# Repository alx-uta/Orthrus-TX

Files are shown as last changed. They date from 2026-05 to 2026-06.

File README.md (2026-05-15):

# Orthrus-TX

OrthrusTx is a custom high-performance RC transmitter platform built around the STM32H745 microcontroller and designed specifically for modern ExpressLRS-based systems. The project focuses on low-latency control, clean mixed-signal hardware design, modular RF integration, and long-term expandability without unnecessary complexity.

The hardware architecture separates critical analog, digital, and RF sections across an 8-layer PCB stackup to improve signal integrity and reduce noise coupling.

## Features

- STM32H745ZIT6 dual-core MCU
- Dual independent ExpressLRS interfaces
- Modular RF daughterboard design
- Precision filtered analog joystick inputs
- USB connectivity
- SD card support
- Rotary encoders and configurable inputs
- Dedicated analog and digital power domains
- Low-noise mixed-signal PCB layout
- Replaceable battery-oriented design

## Design Goals

OrthrusTx prioritizes:

- Low latency
- High reliability
- Electrical cleanliness
- Modular hardware architecture
- Repairability

## Project Vision

OrthrusTx is being developed both as a functional long-range RC transmitter and as a deep embedded hardware/software engineering project focused on performance, architecture, signal integrity, and system-level design.

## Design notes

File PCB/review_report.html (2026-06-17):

# Orthrus-TX — PCB Design Review Report

RC Radio Transmitter Controller | 8-Layer Impedance-Controlled PCB

Project

Orthrus-TX v1.0.0

Schematic Date

2026-03-29

Gerbers Generated

2026-05-19

KiCad Version

10.0.2

Board Size

49.1 × 49.1 mm

Thickness

1.613 mm

Layers

8 (Imp. Ctrl.)

Target Fab

JLCPCB / PCBWay

0

Critical

2

High

4

Medium

5

Low / Info

14

Checks Passed

📋

## Board Overview

Platform: RC Radio Transmitter controller based on STM32H745ZIT6 dual-core Arm Cortex-M7/M4.

Key Interfaces: USB-C (USB 2.0 FS), 2× ELRS RF module connectors, 2× Joystick connectors (6-pin), 2× Encoder connectors (8-pin), Analog potentiometer connector, Digital potentiometer connector, SWD programming header, Battery power input.

Power System: Battery input → reverse-polarity protection (AO3407A P-FET + D1 Schottky) → VCC rail → 4× AP2112K-3.3 LDO (600 mA each) → 3.3 V rails (LD1–LD4). STM32H745 internal SMPS (L1 = 2.2 µH) used for core supply.

EMC: DLW21SN900SQ2L CMC on USB data lines, BLM18AG102SN1D ferrite bead on USB/analog power, 7× SRV05-4 TVS arrays on I/O.

Layer | Name | Cu µm | Diel mm | εr
L1 | F.Cu — SIG TOP | 35 | — | —
— | Prepreg | — | 0.421 | 4.40
L2 | In1.Cu — GND | 30 | — | —
— | Core | — | 0.075 | 3.99
L3 | In2.Cu — POWER | 30 | — | —
— | Prepreg | — | 0.138 | 3.91
L4 | In3.Cu — GND | 30 | — | —
— | Core | — | 0.075 | 3.99
L5 | In4.Cu — ELRS | 30 | — | —
— | Prepreg | — | 0.138 | 3.91
L6 | In5.Cu — GND | 30 | — | —
— | Core | — | 0.075 | 3.99
L7 | In6.Cu — ANALOG | 30 | — | —
— | Prepreg | — | 0.421 | 4.40
L8 | B.Cu — GND | 35 | — | —

Total board thickness: 1.613 mm | Impedance controlled

⚡

## Power Architecture Review

LOW AP2112K-3.3 LDO Dropout at End-of-Discharge — Acts as Implicit Low-Battery Protection LD1–LD4

The AP2112K-3.3 has a worst-case dropout voltage of 300–600 mV at 600 mA, meaning VIN must be ≥ 3.6 V to maintain regulated 3.3 V output. A 1S LiPo discharges from 4.2 V to a hard protection cut-off of ~3.0 V. Below VIN = 3.6 V the LDO output tracks VIN − VDO — the MCU will brownout-reset at approximately VCC ≈ 3.0–3.3 V, which is well above the battery’s 3.0 V over-discharge threshold.

This behaviour acts as implicit low-battery protection: the transmitter will fail-safe (MCU resets) before the battery is deeply discharged. No hardware change is required. Note: the KiCad symbol description states “3.8V–6V input voltage range” — the actual datasheet VIN(min) is 2.5 V; the 3.8 V figure is a worst-case start-up guideline from an application note (see also L1).

Recommended firmware enhancement: Monitor VCC via an MCU ADC input (resistor divider from VCC to a 3.3 V ADC-safe level) and alert the user — LED, display, or telemetry — when VCC drops below ~3.7 V. This provides advance warning before LDO dropout, preventing unexpected mid-flight power loss. Ensure any NVM or flash write operations complete before VCC falls to 3.3 V to avoid data corruption.

HIGH USB Differential Pair Impedance Mismatch — 0.35 mm Traces Give ~140 Ω on 0.421 mm Prepreg J1, L2, R52, R53

The USB_DIFF netclass defines trace width 0.35 mm and gap 0.18 mm. Calculating edge-coupled microstrip impedance for F.Cu routing above L2_GND (H = 0.421 mm, εr = 4.4, T = 35 µm):

Z0 (single-ended, W = 0.35 mm) ≈ 78 Ω

Zdiff (edge-coupled, S = 0.18 mm) ≈ 140 Ω

USB 2.0 requires Zdiff = 90 Ω ±15%. The current routing is approximately 55% too high. To achieve 90 Ω differential on this layer, the trace width must be approximately 0.80 mm (with gap 0.18 mm). The KiCad DRC "unable to find complementary differential pair" warning also suggests the diff pair routing is not correctly coupled.

Action: Correct the USB_DIFF netclass track width to 0.80 mm (or use an impedance calculator for the exact stackup). Re-route J1 USB P/N traces and verify coupling from the connector to the common-mode choke (L2) and series resistors (R52, R53 = 22 Ω). If board space is too tight for 0.8 mm traces near J1, consider routing USB through an inner signal layer between two closely spaced GND planes (L5 between L4_GND and L6_GND at 0.138 mm spacing, which would require much narrower traces but is impractical near the edge connector). Alternatively, accept that this is USB 2.0 Full-Speed (12 Mbps) only and verify by USB compliance testing, since FS is less sensitive to impedance than HS.

MEDIUM SMPS Inductor L1 — Saturation & DCR Specification Unverified L1, LCSC C48945021

L1 (2.2 µH, 0603) is used in the STM32H745 internal SMPS loop (VLXSMPS ↔ VDDSMPS). LCSC part C48945021 is specified as 2.2 µH, which matches ST’s recommendation in AN5188. However, the SMPS output current for core supply can reach 100–200 mA peaks. The inductor must be rated for: saturation current ≥ 300 mA, DCR ≤ 300 mΩ (to limit efficiency loss), and self-resonance frequency well above 2.1 MHz switching frequency.

The specific part number for LCSC C48945021 should be confirmed against its datasheet (rated Isat and DCR are not visible in the schematic fields).

Action: Verify that LCSC C48945021 has Isat ≥ 300 mA and DCR ≤ 300 mΩ. Per ST AN5188, the SMPS inductor placement is also critical — the loop (VLXSMPS, VDDSMPS, VSSSMPS, VFBSMPS) must be as compact as possible with a local 1 µF + 10 nF bypass at VDDSMPS. Confirm these capacitors exist and are placed immediately adjacent to the MCU.

PASS USB-C VDD50USB / VDD33USB Bypass Mode — Valid STM32H745, /LD1_3.3v

Both VDD50USB and VDD33USB are tied to the /LD1_3.3v (3.3 V) rail. Per STM32H745 datasheet §5.1.7, when the application operates entirely at 3.3 V and does not require the 5 V USB transceiver internal supply, VDD50USB may be connected to VDD33USB (both at 3.3 V) in “bypass mode.” This is a valid and documented configuration for USB 2.0 operation.

Action: None — confirmed valid. No hardware change required.

PASS USB-C CC Resistors (5.1 kΩ) — Correct for UFP/Device Mode R41, R42

R41 and R42 = 5.1 kΩ are the CC1/CC2 pull-down (Rd) resistors required by the USB-C specification for an Upstream-Facing Port (device). The USB PD specification mandates Rd = 5.1 kΩ ±10% for device identification. This is correct.

Action: None — correct implementation.

PASS Reverse Polarity Protection — AO3407A P-FET + Schottky D1 U1, D1, POWER_1

AO3407A (P-channel MOSFET, SOT-23-3, Vds = −20 V, Id = −4 A) with a Schottky diode (D1, LCSC C8598, ~SS14) provides low-loss reverse polarity protection on the battery input. The gate drive for U1 is typical for this topology (VBATT on source, GND through gate resistor or direct). This is a well-established approach for LiPo-powered portable devices.

Action: None — correct design.

PASS 4× Independent LDOs for Domain Isolation LD1–LD4

Using four separate AP2112K-3.3 regulators (each 600 mA) to create independent 3.3 V domains (USB/IO, MCU VDD, ELRS, analog) is good practice. This prevents noise coupling between high-current switching loads (ELRS RF) and sensitive analog circuitry. Each domain should have its LDO output capacitor and ferrite bead physically close to the regulator.

Action: Confirm physical placement of each LDO relative to its load domain in PCB layout review.

🔲

## MCU Circuitry Review — STM32H745ZIT6

PASS Crystal Load Capacitors — 12 pF Correct for TSX-3225 24 MHz Y1, C23, C24

TSX-3225 24.0000MF20G-AC3 has a specified load capacitance of CL = 8 pF. Using two 12 pF load capacitors (C23, C24): CL(circuit) = (C1 × C2)/(C1 + C2) + Cstray = (12 × 12)/(24) + ~2 pF = 6 + 2 = 8 pF ✓. The 220 pF capacitor C61 appears to be a CL decoupling aid for the crystal oscillator circuit. Both C23 and C24 use LCSC C882527 (12 pF, 0603, C0G/NP0) — the correct low-tempco dielectric for crystal load capacitors.

Action: None — correct implementation.

PASS VCAP Capacitors Present for STM32H745 Internal LDO VCAP pins, 2.2 µF caps

STM32H745 requires 2.2 µF (minimum) capacitors on VCAP1 (pin 75) and VCAP2 (pin 99), connected directly to GND. Multiple 2.2 µF capacitors (LCSC C23630, 0603) are present in the BOM. These are the internal voltage regulator stabilisation capacitors and are required for proper CPU operation.

Action: Verify in layout that VCAP capacitors are placed within 0.5 mm of the MCU pads with direct GND via connections.

PASS MCU Decoupling Capacitor Network — Well-Defined C3–C62 (various)

The BOM shows a comprehensive decoupling network: 100 nF (LCSC C24452) bulk bypass capacitors, 10 nF (C3836718) high-frequency bypass, 4.7 µF (C19666) bulk capacitors, and 1 µF (C2177011) mid-frequency bypass. This multi-tier bypassing strategy is appropriate for an LQFP-144 MCU at frequencies up to 480 MHz (STM32H745 max CPU clock).

Action: Ensure bypass capacitors are evenly distributed around all four sides of the LQFP-144 package in layout.

MEDIUM BOOT0 Pin Configuration — Pull-Down Resistor Value to Verify BOOT0, R1/R2

The STM32H745 BOOT0 pin must be pulled LOW (to GND) for normal flash boot. R1 and R2 are both 10 kΩ, which appear to be used for BOOT0 control (possibly a pull-down to GND with optional pull-up via programming connector). The STM32H745 internal BOOT0 pull-down is approximately 40 kΩ (weak), so an external pull-down of 10 kΩ is appropriate. Verify the net connectivity ensures BOOT0 is de-asserted during normal power-up.

Action: Confirm that BOOT0 is connected through R1/R2 such that it defaults LOW (GND) at power-on. Ensure the PROGRAMMING_1 connector pins are clearly labelled and that a test plan verifies booting into user flash after programming.

📦

## Bill of Materials Review

HIGH 10 nF Capacitor LCSC Part Number Conflict Between Netlist and CSV BOM C19, C25–C28, C32–C37, C45

The exported CSV BOM groups C19, C25, C26, C27, C28, C32, C33, C34, C35, C36, C37, C45 as 10 nF with LCSC C3836718. However, the netlist (generated 2026-05-31) assigns LCSC C24452 (a 100 nF part) to these same components, while retaining the value field as "10nF". This creates an ordering conflict: purchasing C24452 will yield 100 nF capacitors placed in positions intended for 10 nF.

This discrepancy suggests either (a) the LCSC field was accidentally changed to C24452 for these components without updating the value, or (b) the CSV BOM is stale and the designer intentionally changed them to 100 nF. In either case, the two sources are inconsistent and must be resolved before ordering.

Action: Open the schematic and verify the intended value for C19, C25–C28, C32–C37, C45. If 10 nF: correct the LCSC number to C3836718. If 100 nF: update the value field. Then re-export the BOM and ensure the netlist LCSC field matches. Do not order parts until this is reconciled.

LOW AP2112K-3.3 Symbol Description Overstates Minimum Input Voltage LD1–LD4

The KiCad library description for AP2112K-3.3 states "3.8V–6V input voltage range". The actual AP2112K datasheet (Diodes Inc.) specifies VIN(min) = 2.5 V (absolute minimum) and VOUT(min) + Vdropout as the functional minimum, which is approximately 3.6 V at full load for 3.3 V output. The "3.8V" figure in the library description is a typical worst-case start-up voltage from an older application note and is not an absolute minimum. This mismatch could cause confusion during design review but does not affect function.

Action: Update the KiCad symbol description field to "VIN 2.5V–6V, Vdropout typ 300mV @ 600mA" for clarity. This is a documentation issue only.

LOW Test Points TP1/TP2 Have No LCSC Numbers TP1, TP2

TP1 and TP2 are listed in the BOM without LCSC part numbers. If these are copper pad test points (no physical component), they should be marked DNP (Do Not Place) in the BOM to avoid assembly errors. If they use solderable test point pins, a part number is required.

Action: Mark TP1/TP2 as DNP in the schematic BOM fields if they are bare pad test points. Otherwise, assign the appropriate LCSC part number.

### COMPLETE COMPONENT SUMMARY

Category | Components | Key Values | LCSC | Status
MCU | U3 (STM32H745ZIT6) | LQFP-144, Dual-core H7, 480 MHz | — | OK
LDO Regulator | LD1–LD4 (AP2112K-3.3) | 3.3 V, 600 mA, SOT-23-5 | C23380830 | OK — implicit battery protection
P-FET Protect | U1 (AO3407A) | −20 V / −4 A, SOT-23-3 | — | OK
TVS / ESD | U2–U8 (SRV05-4) | SOT-23-6, 5-line TVS array | — | OK
USB-C Connector | J1 (HRO-TYPE-C-31-M-13x) | USB 2.0, edge-mount, dual-sided fp | C963373 | OK
CMC (USB) | L2 (DLW21SN900SQ2L) | 90 Ω @ 100 MHz, 0805 | C97856 | OK
Ferrite Bead | L3 (BLM18AG102SN1D) | 1 kΩ @ 100 MHz, 0402 | C85824 | OK
SMPS Inductor | L1 (2.2 µH) | 0603, Isat TBD | C48945021 | Verify Isat—see M1
Crystal | Y1 (TSX-3225 24 MHz) | 24.0000 MHz, ±20 ppm, 3.2×2.5 | — | OK
Schottky Diode | D1 | SOD-123, 40V 1A (C8598) | C8598 | OK
ELRS Connectors | ELRS_1, ELRS_2 (5034800800) | 8-pin 0.5 mm FPC, Molex | C293338 | OK
Joystick Connectors | JOYSTICK_1/2 (532610671) | 6-pin 0.5 mm FPC, Molex | C17393620 | OK
Encoder Connectors | ENCODER_1/2 (532610871) | 8-pin 0.5 mm FPC, Molex | C293349 | OK
Power Connector | POWER_1 (532610371) | 3-pin 0.5 mm FPC, Molex | C293630 | OK
Prog. Connector | PROGRAMMING_1 (532610871) | 8-pin 0.5 mm FPC (SWD+UART) | C293349 | OK
10 nF Caps | C19, C25–C28, C32–C37, C45 | 0603, 10 nF | CONFLICT | Resolve—see H3
100 nF Caps | C4–C16, C21, C31, C38, etc. | 0603, 100 nF, C24452 | C24452 | OK
4.7 µF Caps | C3, C17, C29, C40 | 0603, 4.7 µF, C19666 | C19666 | OK
2.2 µF Caps (VCAP) | C18, C30, C59, C63, C64 | 0603, 2.2 µF, C23630 | C23630 | OK
1 µF Caps | C20, C42–C44, C46, C49 | 0603, 1 µF, C2177011 | C2177011 | OK
USB Series Resistors | R52, R53 | 22 Ω, 0603 | — | OK
Pull-up / Pull-down | R1, R2 (10 kΩ), R13–R25 (10 kΩ) | 0603 | C95204 | OK
Series Damping R | R3–R12 (100 Ω) | 0603 | C122970 | OK
Crystal Load Caps | C23, C24 (12 pF) | 0603, C0G/NP0, C882527 | C882527 | OK
Test Points | TP1, TP2 | — | missing | Mark DNP or add PN

🗺️

## PCB Layout Review

MEDIUM One Undocumented DRC Clearance Exclusion Exclusion @ 165.19, 39.88 mm

One DRC clearance exclusion is present in the project:

clearance | 165190000 | 39883600 | eac3491a-4f87-4dbb-a5c6-cd6bd29327cf | 1b6a4981-23e8-49ef-a873-3edf5f8e6c4b

The board coordinates (165.19 mm X, 39.88 mm Y) are outside the board outline (49.1 × 49.1 mm), suggesting this exclusion may be from an older revision or template and is stale. Stale DRC exclusions mask real violations if the board geometry changes.

Action: Open the DRC dialog in KiCad, inspect this exclusion, identify the two items it involves (GUIDs provided), and either document why the clearance violation is acceptable or delete the exclusion if it is stale.

MEDIUM USB-C Connector Edge Clearance Exception — Fragility Risk J1, DRC rule edge_J1_exception

A custom DRC rule permits J1 (USB-C) pads to be only 0.1 mm from the board edge, compared to the standard 0.3 mm edge clearance rule. The HRO-TYPE-C-31-M-13x is an edge-mount USB-C receptacle, so some pads will naturally approach the board edge. However, 0.1 mm clearance to the milled edge is extremely tight. Most PCB fabs quote a ±0.1 mm router tolerance, meaning the copper could be exposed or cut in a worst-case scenario.

Action: Confirm with your target fab (JLCPCB / PCBWay) that their edge routing tolerance and their minimum copper-to-edge for edge-mount connectors allows 0.1 mm. Consider adding a copper-free keepout around the J1 footprint edge pads if the fab requires 0.15 mm or larger clearance. Verify with the gerber viewer that edge pads are not overlapping the board outline.

PASS 8-Layer Stackup Provides Excellent Shielding and Power Integrity

Four dedicated GND planes (L2, L4, L6, L8) ensure every signal layer (L1, L5, L7) and the power plane (L3) has an adjacent GND reference, minimising return path inductance. The ELRS RF signals are isolated on L5 (between L4-GND and L6-GND), providing natural shielding for sensitive RF traces. The analog layer (L7) is adjacent to the bottom GND (L8), ideal for low-noise ADC signal routing.

Action: None — excellent layer assignment strategy.

PASS Teardrops Enabled on All Pad Types

Teardrops are enabled for PTH pads, SMD pads, and vias (as seen in .kicad_pro). Teardrops improve mechanical reliability at the pad-to-trace junction and reduce acid traps during etching, which is particularly important for the fine-pitch LQFP-144 STM32 pads.

Action: None — good DFM practice.

LOW DRC Diff Pair Rule Gap Limits May Not Match Actual Routing .kicad_dru, USB_DIFF netclass

The DRU specifies USB_DIFF diff pair gap min 0.10 mm, max 0.20 mm. The netclass in .kicad_pro shows diff_pair_dimensions with gap = 0 and width = 0 (default/placeholder values). If the diff pair was not routed using KiCad’s interactive diff pair router, these constraints will not have been enforced during routing, and the DRC “unable to find complementary diff pair” warning confirms this.

Action: After correcting the track width to ~0.80 mm (see HIGH finding), re-route using the KiCad interactive diff pair router so that gap constraints are automatically enforced. Set the diff_pair_dimensions entry with explicit gap (0.18 mm) and width (0.80 mm) values so DRC can validate the result.

LOW Gerber Job File Missing Surface Finish and PCB Revision Orthrus-TX-job.gbrjob

The gerber job file lists "Finish": "None" and the PCB revision field reads "rev?". For fabrication submission, the finish must be specified (HASL, ENIG, OSP, etc.) and a proper revision identifier should be filled in. ENIG is recommended for the fine-pitch LQFP-144 and 0.5 mm FPC connector footprints to ensure reliable soldering.

Action: Set the board finish in KiCad Board Setup → Board Stackup to “ENIG” (or intended finish) and update the revision field before final gerber export.

📡

## EMC / Signal Integrity Review

PASS USB Common-Mode Filtering — DLW21SN900SQ2L + BLM18AG102SN1D L2, L3, J1

DLW21SN900SQ2L is a 2-line common-mode choke (90 Ω @ 100 MHz, 0805) on the USB D+/D− lines — the correct component for suppressing common-mode interference on USB 2.0. BLM18AG102SN1D (1 kΩ @ 100 MHz ferrite bead) on the USB VBUS/power supply rail further reduces conducted EMI into the MCU. This is a textbook USB EMI filter topology.

Action: Ensure L2 is placed as close as possible to J1 (within 5 mm), before the 22 Ω series resistors R52/R53. Filter placement order from connector: J1 → L2 (CMC) → L3 (ferrite, VBUS) → R52/R53 → STM32.

PASS 7× SRV05-4 ESD Arrays for I/O Protection U2–U8

Seven SRV05-4 (5-line TVS diode array, SOT-23-6, 5 V clamping) instances provide ESD protection on connector I/O lines. This is good practice for an RC transmitter that interfaces with external modules (ELRS, joysticks, encoders) which may be hot-plugged in the field. SRV05-4 has a typical capacitance of ~1 pF per line, which is negligible at the signal speeds used.

Action: Ensure ESD devices are placed between the connector and the MCU/internal circuitry (not after), with short traces to a local via stitched to GND.

PASS ELRS RF Isolation — Dedicated Layer L5 with GND Sandwich

ELRS (ExpressLRS) RF module signals are routed on L5 (In4.Cu), sandwiched between L4_GND and L6_GND. This provides excellent shielding for 900 MHz / 2.4 GHz RF traces and reduces coupling into the analog and digital domains. Dedicated GND layers above and below the RF signal layer is the correct approach for RF PCB design.

Action: Verify that stitching vias connect L4_GND to L6_GND around the ELRS connector area to form a Faraday cage effect for the RF traces.

PASS Analog Domain Separation — Dedicated Layer L7 with GND Reference

Joystick potentiometer signals and ADC inputs are routed on L7 (In6.Cu — ANALOG), adjacent to the L8 bottom GND plane. This gives a clean reference for analog signals and minimises coupling from switching digital signals. The 10 kΩ pull-up resistors on ADC input lines (R3–R12, 100 Ω series damping) further protect the MCU ADC inputs.

Action: Ensure the LDO domain supplying the MCU VDDA pin routes through L3_POWER and that the VDDA bypass capacitors are not shared with noisy digital supplies.

🏭

## Design for Manufacturing (DFM)

Item | Requirement | Design Value | Status
Min track width | 0.10 mm (DRU) / JLCPCB 0.09 mm min | 0.15 mm (rule) / 0.10 mm (DRU) | OK
Min track spacing | 0.10 mm (JLCPCB) | 0.15 mm (rule) | OK
Min via drill | 0.20 mm (DRU) — JLCPCB 8L: 0.20 mm | 0.20 mm | OK
Min via diameter | 0.40 mm (DRU) | 0.40 mm | OK
Annular ring | 0.10 mm (DRU) | 0.10 mm | OK
Hole-to-hole (diff net) | 0.50 mm (DRU) | 0.50 mm | OK
Edge clearance | 0.30 mm (general) / 0.10 mm (J1) | Rule-defined | Verify J1 with fab
Component package | All passives 0603 minimum | All 0603 | OK — consistent
FPC connectors | 0.5 mm pitch Molex (all connectors) | All 0.5 mm FPC | OK
PCB surface finish | ENIG recommended (0.5mm FPC pads) | Not specified | Specify in setup
Board size | 49.1 × 49.1 mm | 49.1 × 49.1 mm | OK
Layer count | 8 layers (impedance controlled) | 8 layers | OK — JLC/PCBWay capable
Soldermask | Both sides (F.Mask, B.Mask) | Gerbers present | OK
Silkscreen | Both sides | Gerbers present (F + B) | OK
Drill files | PTH + NPTH separate | Separate .drl files | OK

📊

## Findings Summary

# | Severity | Title | Section | Action Required Before Fab?

H1 | LOW | AP2112K-3.3 LDO dropout at end-of-discharge — acts as implicit low-battery protection; firmware ADC monitoring recommended | Power | No — firmware enhancement only
H2 | HIGH | USB diff pair impedance ~140 Ω vs 90 Ω target — trace width too narrow | Power / PCB | Yes — correct trace width to ~0.80 mm or accept FS-only with compliance test
H3 | HIGH | 10 nF cap LCSC numbers conflict between netlist and BOM CSV | BOM | Yes — must resolve before ordering parts
M1 | MEDIUM | SMPS inductor L1 saturation current / DCR unverified | Power | Yes — verify datasheet for LCSC C48945021
M2 | MEDIUM | BOOT0 pin pull-down configuration to be confirmed | MCU | Yes — verify net connectivity
M4 | MEDIUM | Stale DRC clearance exclusion at off-board coordinates | PCB | Recommended — clean up before production sign-off
M5 | MEDIUM | J1 USB-C edge clearance 0.1 mm — confirm with fab tolerance | PCB / DFM | Yes — get fab confirmation
L1 | LOW | AP2112K-3.3 library description misstates VIN(min) | BOM | No — documentation only
L2 | LOW | TP1/TP2 missing LCSC numbers / no DNP marker | BOM | Recommended before ordering
L3 | LOW | DRC diff pair dimension entries are default (0) values | PCB | After USB re-route
L4 | LOW | Gerber job missing surface finish and PCB revision | DFM | Yes — set before fab submission

✅

## Recommended Next Steps (Priority Order)

1. [H3] Reconcile 10 nF capacitor LCSC part numbers — open schematic, fix C19/C25–C28/C32–C37/C45, re-export BOM and netlist.
2. [H2] Correct USB diff pair trace width — change USB_DIFF netclass track width to ~0.80 mm, re-route with interactive diff pair router, run DRC to confirm 90 Ω routing, and run DRC with no diff pair warnings.
3. [M2] Verify BOOT0 default state — trace R1/R2 connectivity to confirm BOOT0 is LOW at power-on.
4. [M1] Verify L1 inductor specification — confirm LCSC C48945021 datasheet: Isat ≥ 300 mA, DCR ≤ 300 mΩ.
5. [M4] Clear stale DRC exclusion — open DRC, delete the off-board coordinate exclusion if stale.
6. [M5] Confirm J1 edge clearance with fab — email JLCPCB/PCBWay with the 0.1 mm edge clearance question before ordering.
7. [H1/L] Firmware low-battery warning — add ADC monitoring of VCC via resistor divider; alert user (LED/display/telemetry) at VCC ≈ 3.7 V before LDO dropout. Protect flash writes against VCC < 3.3 V.
8. [L4] Update gerber job file — set finish to ENIG, set PCB revision, re-export gerbers.
9. [L2] Mark TP1/TP2 as DNP — update BOM fields.

Orthrus-TX Hardware Design Review | Generated by GitHub Copilot design review analysis | KiCad 10.0.2 | Review date: 2026-05-31

This report is based on static analysis of KiCad project files (schematic, PCB, BOM, DRU rules, gerbers). Physical verification, SPICE simulation, and compliance testing are outside the scope of this review.

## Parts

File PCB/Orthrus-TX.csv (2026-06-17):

Reference | Value | DNP | Footprint | LCSC
BUTTONS_1 | 532610471 |  | Custom-Library:CONN_532610001-SD_04_MOL | C696092
BUZZER_1 | 532610271 |  | Custom-Library:CONN_532610001-SD_02_MOL | C177225
C1,C3,C17,C29,C40 | 4.7µF |  | Capacitor_SMD:C_0603_1608Metric | C19666
C2,C18,C30,C59,C63,C64 | 2.2µF |  | Capacitor_SMD:C_0603_1608Metric | C23630
C4,C5,C6,C7,C8,C9,C10,C11,C12,C13,C14,C15,C16,C21,C31,C38,C41,C47,C48,C50,C52,C53,C54,C55,C56,C57,C58,C60,C62 | 100nF |  | Capacitor_SMD:C_0603_1608Metric | C24452
C19,C25,C26,C27,C28,C32,C33,C34,C35,C36,C37,C45 | 10nF |  | Capacitor_SMD:C_0603_1608Metric | C3836718
C20,C42,C43,C44,C46,C49 | 1µF |  | Capacitor_SMD:C_0603_1608Metric | C2177011
C22,C51 | 10µF |  | Capacitor_SMD:C_0603_1608Metric | C19702
C23,C24 | 12pF |  | Capacitor_SMD:C_0603_1608Metric | C882527
C39 | 22µF |  | Capacitor_SMD:C_0603_1608Metric | C2762594
C61 | 220pF |  | Capacitor_SMD:C_0603_1608Metric | C882575
ELRS_1,ELRS_2 | 5034800800 |  | Custom-Library:CON_5034800800_MOL | C293338
ENCODER_1,ENCODER_2,POT_ANALOG_1,PROGRAMMING_1,SCREEN_1 | 532610871 |  | Custom-Library:CONN_532610001-SD_08_MOL | C293349
J1 | HRO-TYPE-C-31-M-13x |  | Custom-Library:Molex-216990_GCT-USB45xx_HRO-TYPE-C-31-M-13x-PiMicro_1_DOUBLESIDED | C963373
JOYSTICK_1,JOYSTICK_2,SWITCHES_1 | 532610671 |  | Custom-Library:CONN_532610001-SD_06_MOL | C17393620
L1 | 2.2uH |  | Inductor_SMD:L_0603_1608Metric | C48945021
L2 | DLW21SN900SQ2L |  | Custom-Library:IND_DLW21S_0805_MUR | C97856
L3 | BLM18AG102SN1D |  | Custom-Library:BLM18_MUR | C85824
LD1,LD2,LD3,LD4 | AP2112K-3.3 |  | Package_TO_SOT_SMD:SOT-23-5 | C23380830
POT_DIGITAL_1 | 532610771 |  | Custom-Library:CONN_532610001-SD_07_MOL | C505276
POWER_1 | 532610571 |  | CONN_532610001-SD_05_MOL
R1,R2,R13,R14,R15,R16,R17,R18,R19,R20,R21,R22,R23,R24,R25,R26,R27,R28,R29,R30,R31,R32,R33,R34,R35,R36,R37,R38,R39,R40,R47,R51 | 10kΩ |  | Resistor_SMD:R_0603_1608Metric | C95204
R3,R4,R5,R6,R7,R8,R9,R10,R11,R12,R56 | 100Ω |  | Resistor_SMD:R_0603_1608Metric | C122970
R41,R42 | 5.1kΩ |  | Resistor_SMD:R_0603_1608Metric | C122969
R43,R44,R57 | 100kΩ |  | Resistor_SMD:R_0603_1608Metric | C122538
R45,R46,R48,R49 | 47kΩ |  | Resistor_SMD:R_0603_1608Metric | C491223
R50,R58,R59,R60,R61,R62 | 33Ω |  | Resistor_SMD:R_0603_1608Metric | C403478
R52,R53 | 22Ω |  | Resistor_SMD:R_0603_1608Metric | C2907129
R54 | 47Ω |  | Resistor_SMD:R_0603_1608Metric | C403245
R55 | 1MΩ |  | Resistor_SMD:R_0603_1608Metric | C491226
SD_CARD_1 | 1040310811 |  | Custom-Library:104031-0811_MOL | C585350
STM32H745ZIT6 | STM32H745ZITx |  | Package_QFP:LQFP-144_20x20mm_P0.5mm | C730193
TP1 | BFF_1 |  | TestPoint:TestPoint_Pad_1.0x1.0mm
TP2 | BFF_2 |  | TestPoint:TestPoint_Pad_1.0x1.0mm
U1 | AO3407A |  | Custom-Library:SOT-23-3L_AOS | C15127
U2,U3,U4,U5,U6,U7,U8 | SRV05-4 |  | Custom-Library:SOT-23-6 | C558418
XTAL1 | TSX-3225 24.0000MF20G-AC3 |  | Custom-Library:TSX-3225 24.0000MF20G-AC3_EPS | C2650460

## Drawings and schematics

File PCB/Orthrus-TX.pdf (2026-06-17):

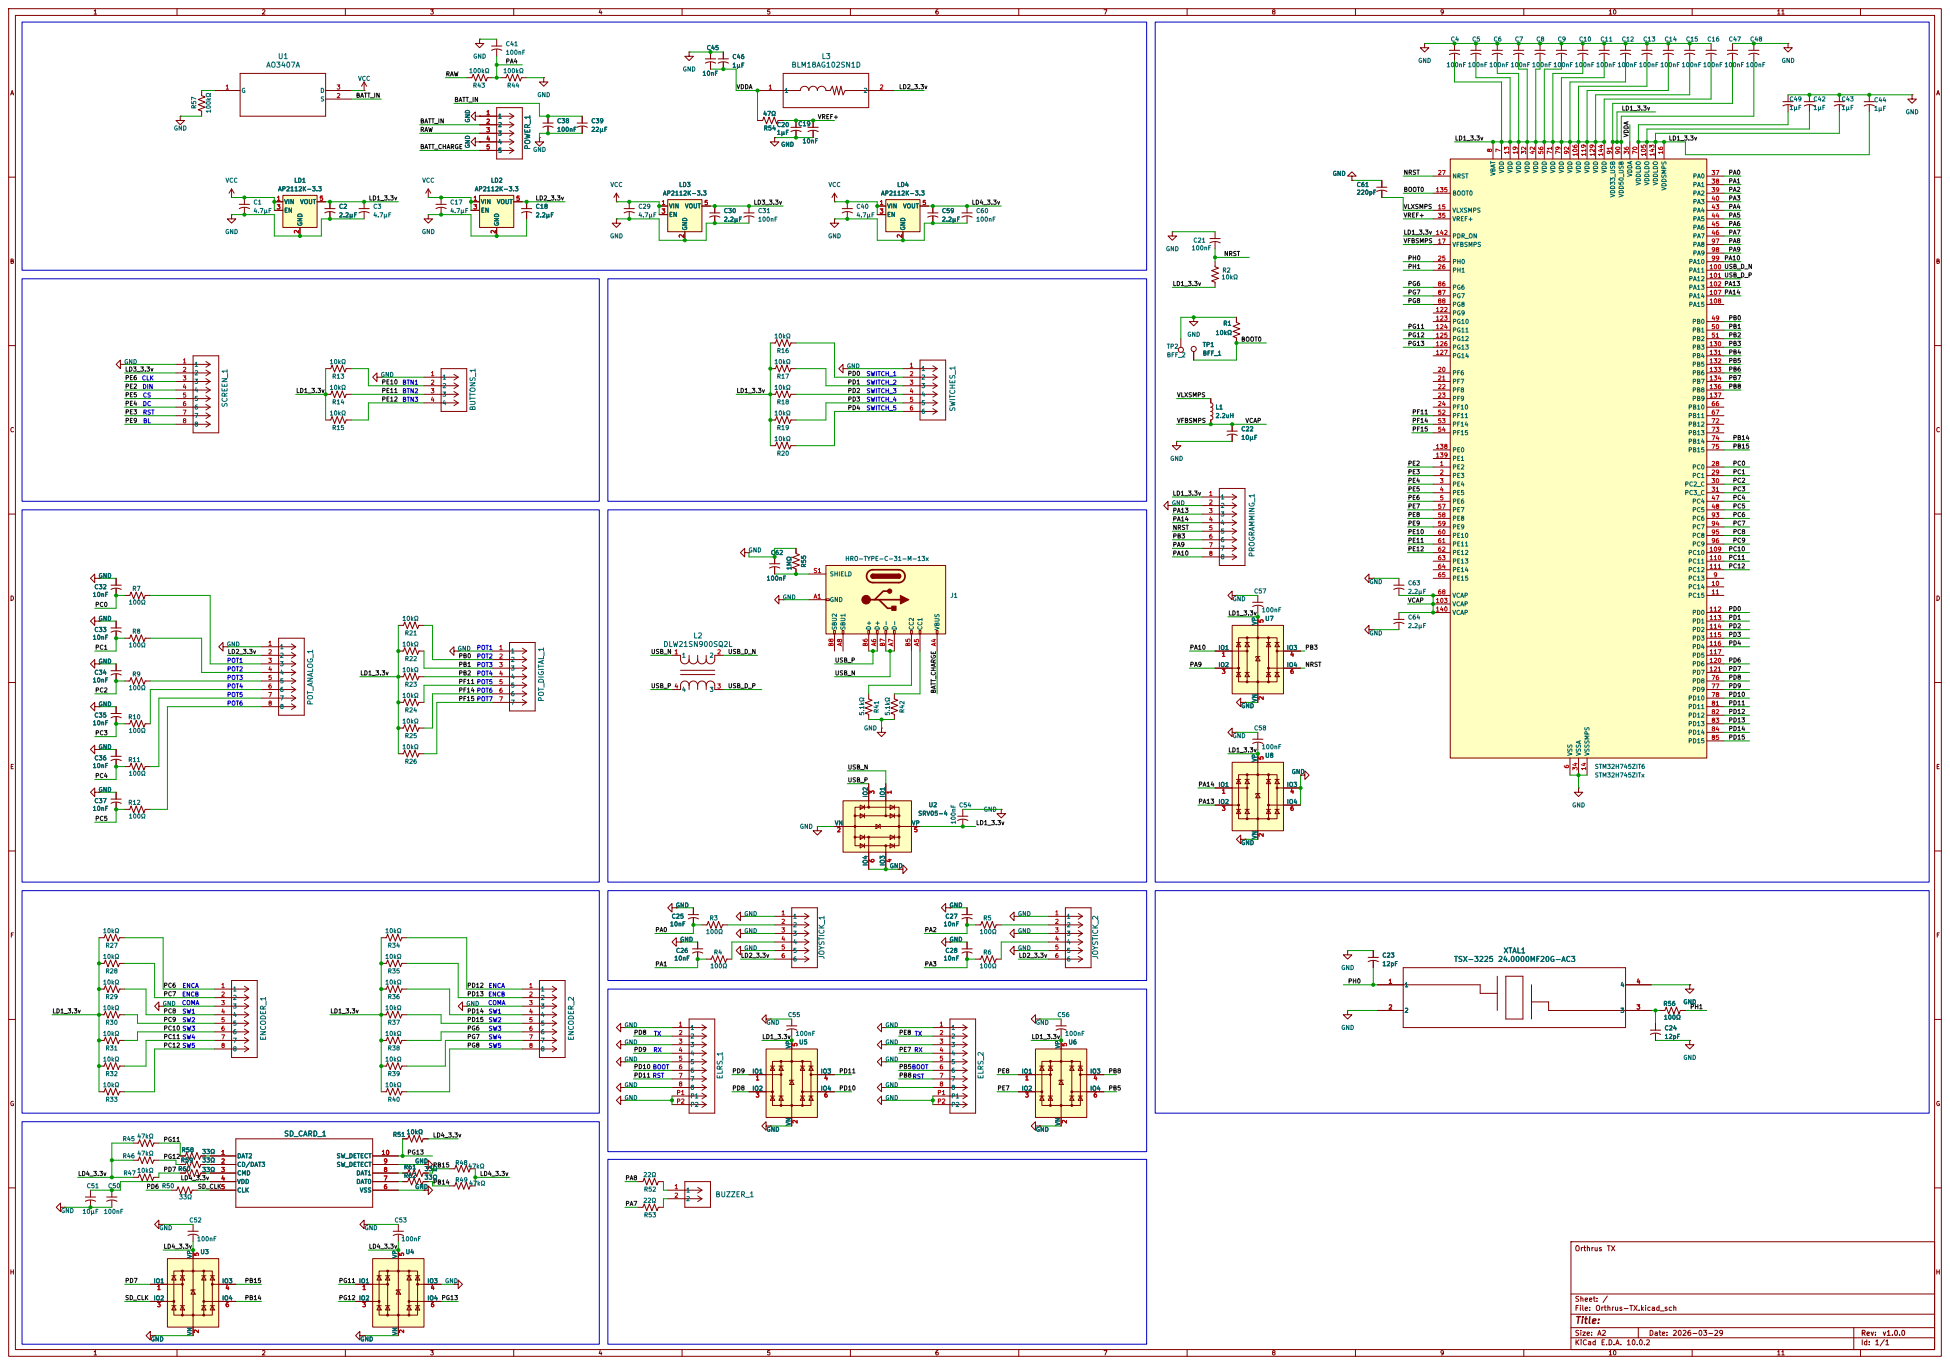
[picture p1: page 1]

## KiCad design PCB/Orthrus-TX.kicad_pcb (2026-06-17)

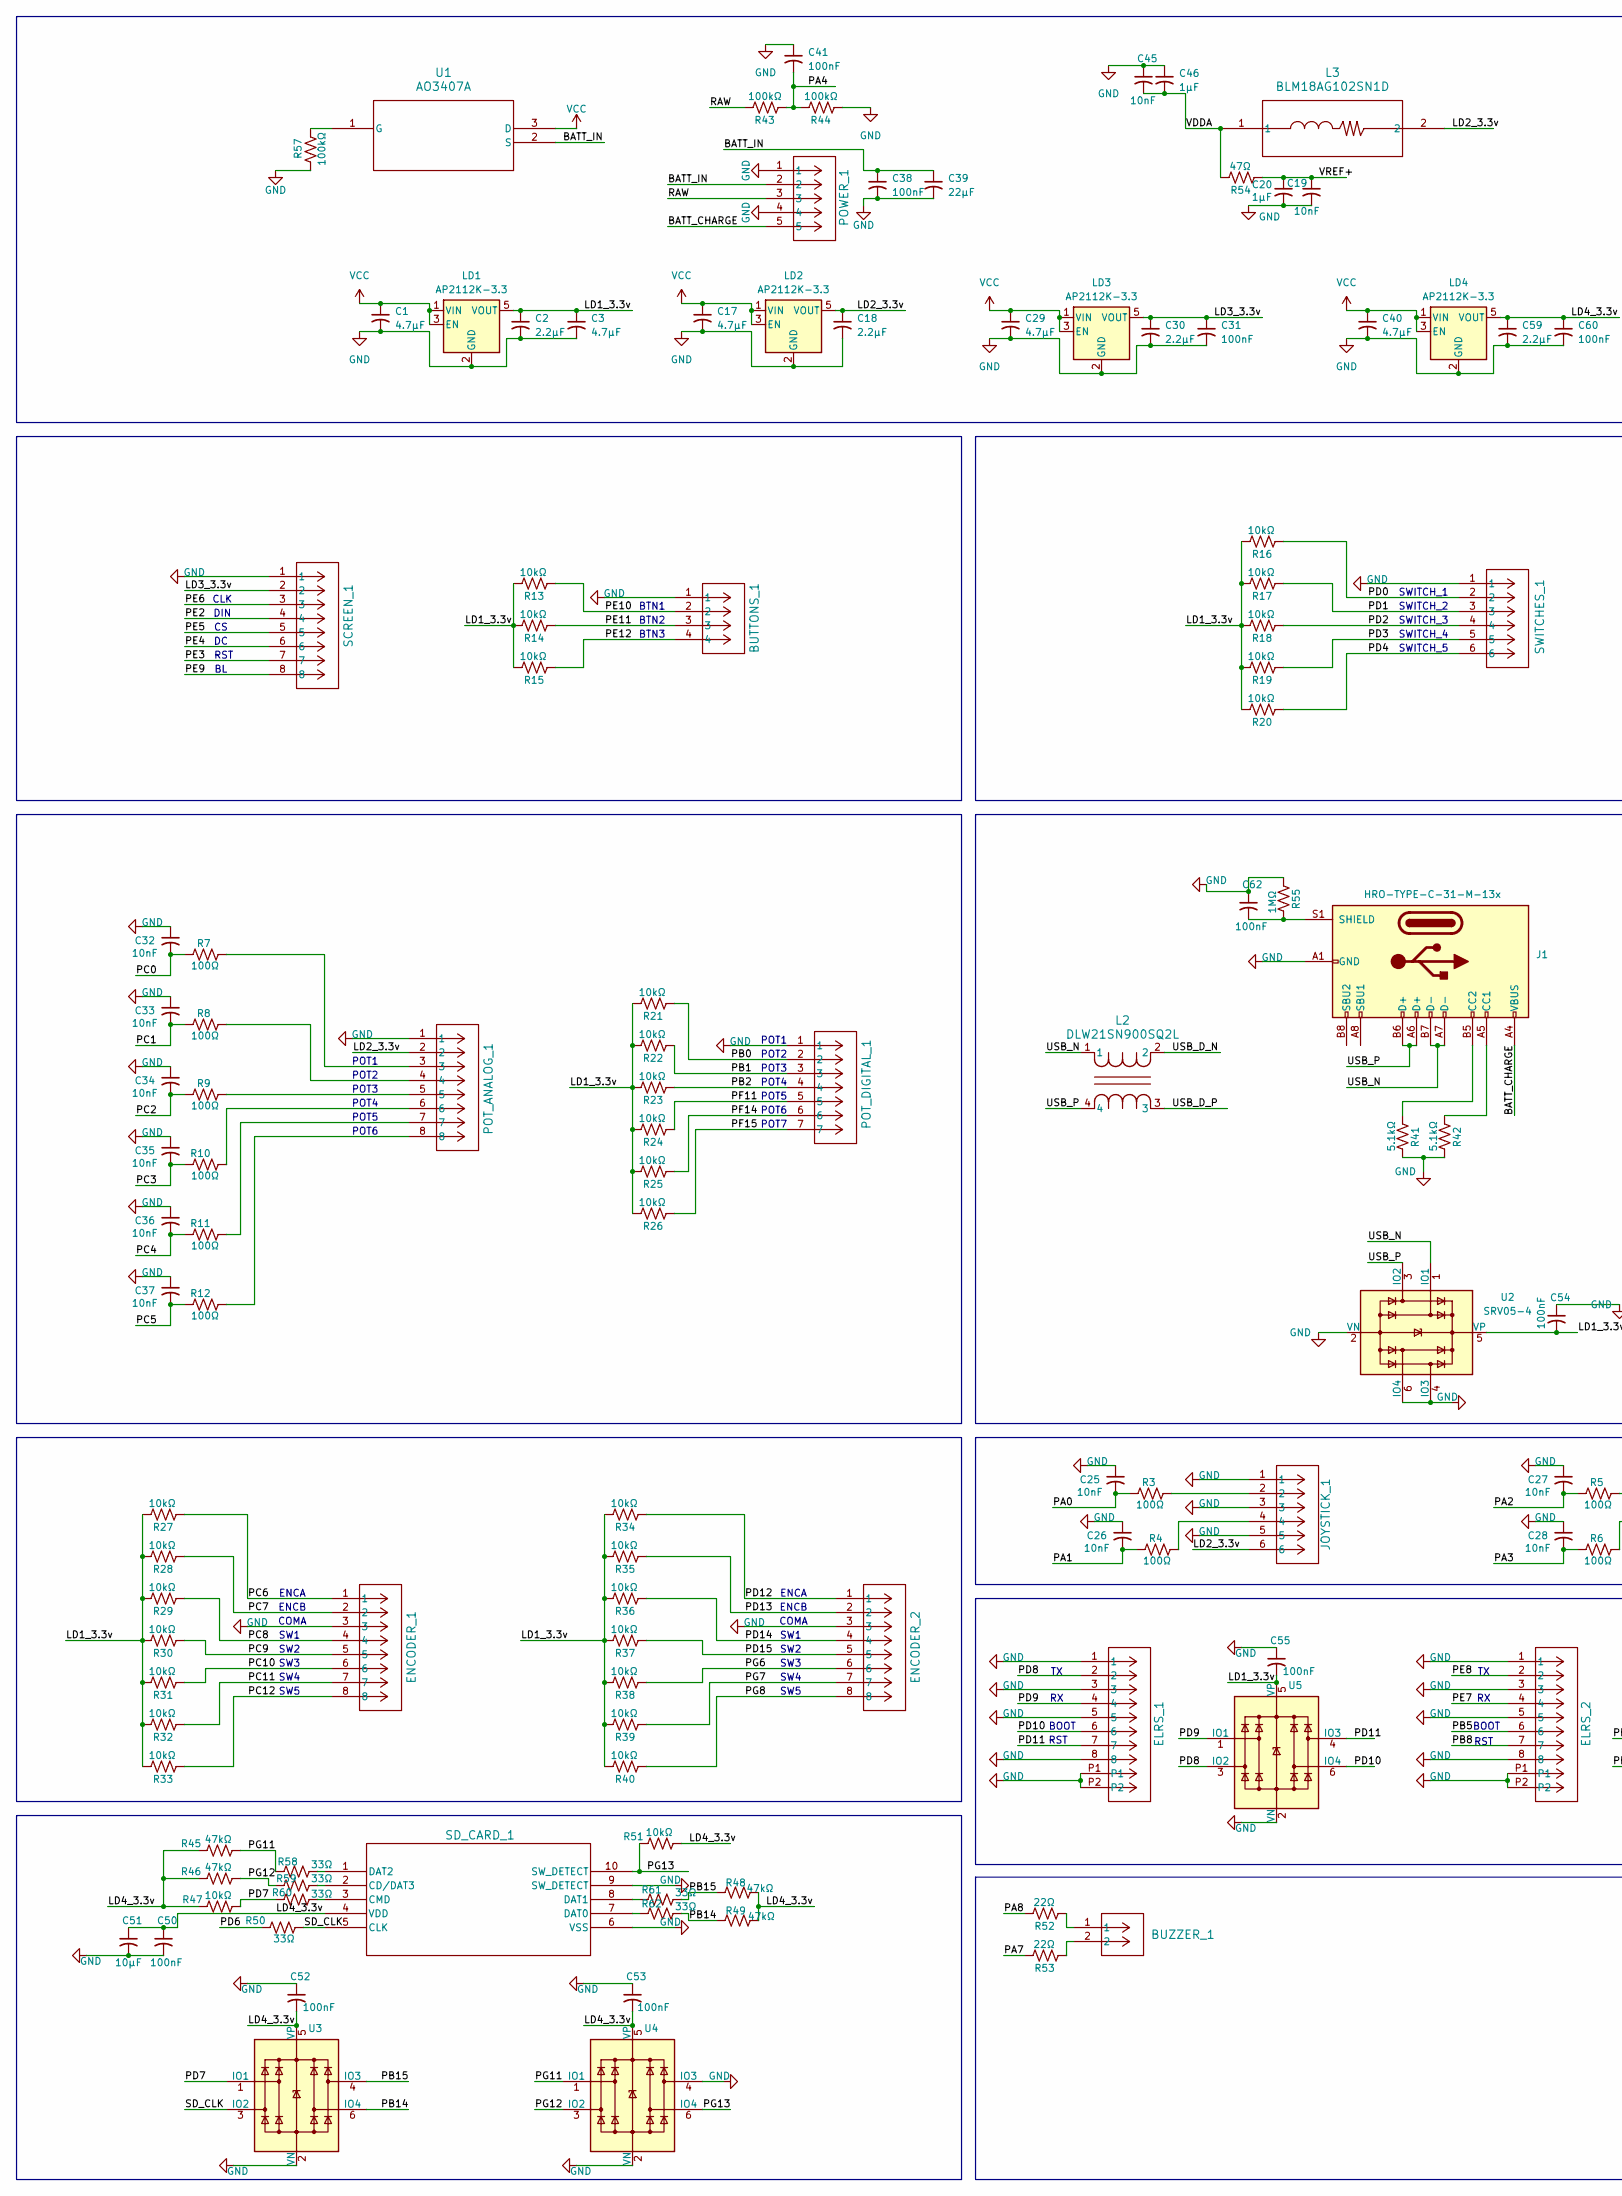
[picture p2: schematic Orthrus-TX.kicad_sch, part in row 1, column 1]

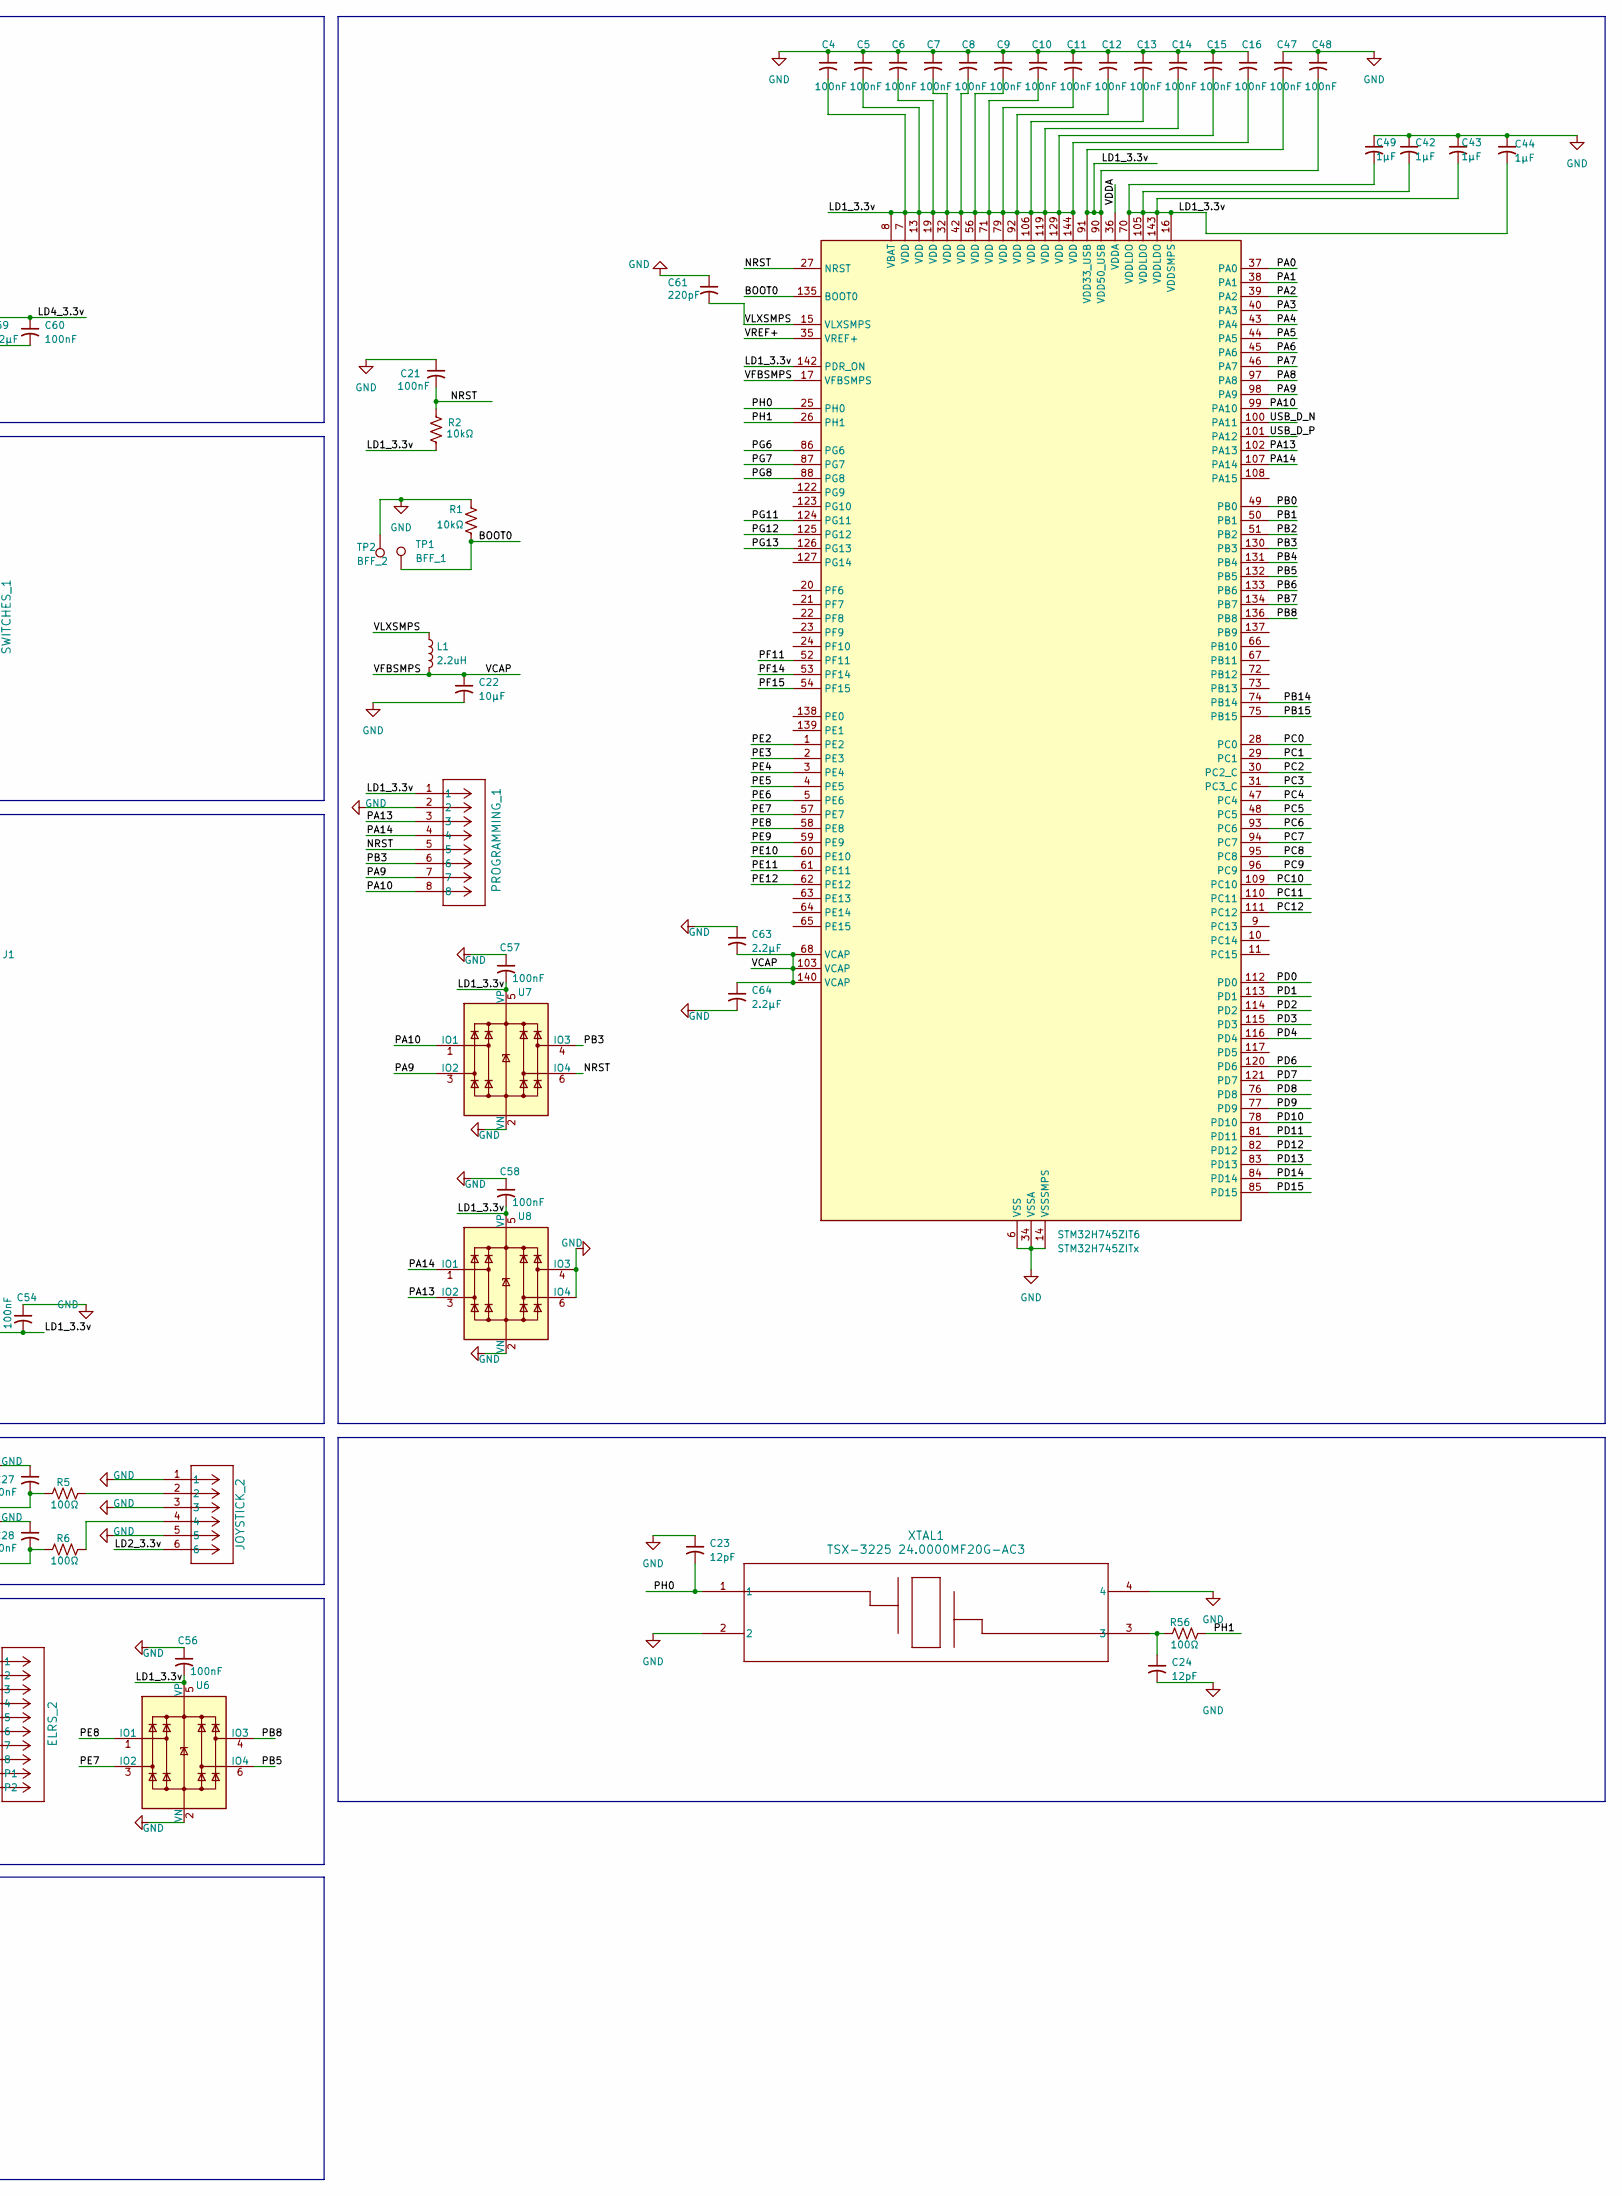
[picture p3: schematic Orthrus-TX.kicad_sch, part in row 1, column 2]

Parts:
BUTTONS_1: 532610471; CONN_532610001-SD_04_MOL; LCSC C696092
BUZZER_1: 532610271; CONN_532610001-SD_02_MOL; LCSC C177225
C1, C3, C17, C29, C40: 4.7µF; C_0603_1608Metric; LCSC C19666
C2, C18, C30, C59, C63, C64: 2.2µF; C_0603_1608Metric; LCSC C23630
C4, C5, C6, C7, C8, C9, C10, C11, C12, C13, C14, C15, C16, C21, C31, C38, C41, C47, C48, C50, C52, C53, C54, C55, C56, C57, C58, C60, C62: 100nF; C_0603_1608Metric; LCSC C24452
C19, C25, C26, C27, C28, C32, C33, C34, C35, C36, C37, C45: 10nF; C_0603_1608Metric; LCSC C3836718
C20, C42, C43, C44, C46, C49: 1µF; C_0603_1608Metric; LCSC C2177011
C22, C51: 10µF; C_0603_1608Metric; LCSC C19702
C23, C24: 12pF; C_0603_1608Metric; LCSC C882527
C39: 22µF; C_0603_1608Metric; LCSC C2762594
C61: 220pF; C_0603_1608Metric; LCSC C882575
ELRS_1, ELRS_2: 5034800800; CON_5034800800_MOL; LCSC C293338
ENCODER_1, ENCODER_2: 532610871; CONN_532610001-SD_08_MOL; LCSC C293349
J1: HRO-TYPE-C-31-M-13x; Molex-216990_GCT-USB45xx_HRO-TYPE-C-31-M-13x-PiMicro_1_DOUB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; LCSC C963373
JOYSTICK_1, JOYSTICK_2: 532610671; CONN_532610001-SD_06_MOL; LCSC C17393620
L1: 2.2uH; L_0603_1608Metric; LCSC C48945021
L2: DLW21SN900SQ2L; IND_DLW21S_0805_MUR; LCSC C97856
L3: BLM18AG102SN1D; BLM18_MUR; LCSC C85824
LD1, LD2, LD3, LD4: AP2112K-3.3; SOT-23-5; LCSC C23380830
POT_ANALOG_1: 532610871; CONN_532610001-SD_08_MOL; LCSC C293349
POT_DIGITAL_1: 532610771; CONN_532610001-SD_07_MOL; LCSC C505276
POWER_1: 532610571; CONN_532610001-SD_05_MOL
PROGRAMMING_1: 532610871; CONN_532610001-SD_08_MOL; LCSC C293349
R1, R2, R13, R14, R15, R16, R17, R18, R19, R20, R21, R22, R23, R24, R25, R26, R27, R28, R29, R30, R31, R32, R33, R34, R35, R36, R37, R38, R39, R40, R47, R51: 10kΩ; R_0603_1608Metric; LCSC C95204
R3, R4, R5, R6, R7, R8, R9, R10, R11, R12, R56: 100Ω; R_0603_1608Metric; LCSC C122970
R41, R42: 5.1kΩ; R_0603_1608Metric; LCSC C122969
R43, R44, R57: 100kΩ; R_0603_1608Metric; LCSC C122538
R45, R46, R48, R49: 47kΩ; R_0603_1608Metric; LCSC C491223
R50, R58, R59, R60, R61, R62: 33Ω; R_0603_1608Metric; LCSC C403478
R52, R53: 22Ω; R_0603_1608Metric; LCSC C2907129
R54: 47Ω; R_0603_1608Metric; LCSC C403245
R55: 1MΩ; R_0603_1608Metric; LCSC C491226
SCREEN_1: 532610871; CONN_532610001-SD_08_MOL; LCSC C293349
SD_CARD_1: 1040310811; 104031-0811_MOL; LCSC C585350
STM32H745ZIT6: STM32H745ZITx; LQFP-144_20x20mm_P0.5mm; LCSC C730193
SWITCHES_1: 532610671; CONN_532610001-SD_06_MOL; LCSC C17393620
TP1: BFF_1; TestPoint_Pad_1.0x1.0mm
TP2: BFF_2; TestPoint_Pad_1.0x1.0mm
U1: AO3407A; SOT-23-3L_AOS; LCSC C15127
U2, U3, U4, U5, U6, U7, U8: SRV05-4; SOT-23-6; LCSC C558418
XTAL1: TSX-3225 24.0000MF20G-AC3; TSX-3225 24.0000MF20G-AC3_EPS; LCSC C2650460

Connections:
/BATT_CHARGE: J1.A4 (VBUS), J1.A9 (VBUS), J1.B4 (VBUS), J1.B9 (VBUS), POWER_1.5
/BATT_IN: C38.1, C39.1, POWER_1.2, U1.2 (S)
/BOOT0: R1.2, STM32H745ZIT6.135 (BOOT0), TP1.1 (1_1)
/LD1_3.3v: C2.1, C3.1, C4.2, C5.2, C6.2, C7.2, C8.2, C9.2, C10.2, C11.2, C12.2, C13.2, C14.2, C15.2, C16.2, C42.2, C43.2, C44.2, C47.2, C48.2, C49.2, C54.2, C55.2, C56.2, C57.2, C58.2, LD1.5 (VOUT), PROGRAMMING_1.1, R2.2, R13.2, R14.2, R15.2, R16.2, R17.2, R18.2, R19.2, R20.2, R21.2, R22.2, R23.2, R24.2, R25.2, R26.2, R27.2, R28.2, R29.2, R30.2, R31.2, R32.2, R33.2, R34.2, R35.2, R36.2, R37.2, R38.2, R39.2, R40.2, STM32H745ZIT6.7 (VDD), STM32H745ZIT6.8 (VBAT), STM32H745ZIT6.13 (VDD), STM32H745ZIT6.16 (VDDSMPS), STM32H745ZIT6.19 (VDD), STM32H745ZIT6.32 (VDD), STM32H745ZIT6.42 (VDD), STM32H745ZIT6.56 (VDD), STM32H745ZIT6.70 (VDDLDO), STM32H745ZIT6.71 (VDD), STM32H745ZIT6.79 (VDD), STM32H745ZIT6.90 (VDD50_USB), STM32H745ZIT6.91 (VDD33_USB), STM32H745ZIT6.92 (VDD), STM32H745ZIT6.105 (VDDLDO), STM32H745ZIT6.106 (VDD), STM32H745ZIT6.119 (VDD), STM32H745ZIT6.129 (VDD), STM32H745ZIT6.142 (PDR_ON), STM32H745ZIT6.143 (VDDLDO), STM32H745ZIT6.144 (VDD), U2.5 (VP), U5.5 (VP), U6.5 (VP), U7.5 (VP), U8.5 (VP)
/LD2_3.3v: C18.1, JOYSTICK_1.6, JOYSTICK_2.6, L3.2, LD2.5 (VOUT), POT_ANALOG_1.2
/LD3_3.3v: C30.1, C31.1, LD3.5 (VOUT), SCREEN_1.2
/LD4_3.3v: C50.1, C51.1, C52.2, C53.2, C59.1, C60.1, LD4.5 (VOUT), R45.2, R46.2, R47.2, R48.1, R49.1, R51.1, SD_CARD_1.4 (VDD), U3.5 (VP), U4.5 (VP)
/NRST: C21.2, PROGRAMMING_1.5, R2.1, STM32H745ZIT6.27 (NRST), U7.6 (IO4)
/PA0: C25.2, R3.1, STM32H745ZIT6.37 (PA0)
/PA1: C26.2, R4.1, STM32H745ZIT6.38 (PA1)
/PA2: C27.2, R5.1, STM32H745ZIT6.39 (PA2)
/PA3: C28.2, R6.1, STM32H745ZIT6.40 (PA3)
/PA4: C41.2, R43.2, R44.1, STM32H745ZIT6.43 (PA4)
/PA5: STM32H745ZIT6.44 (PA5)
/PA6: STM32H745ZIT6.45 (PA6)
/PA7: R53.1, STM32H745ZIT6.46 (PA7)
/PA8: R52.1, STM32H745ZIT6.97 (PA8)
/PA9: PROGRAMMING_1.7, STM32H745ZIT6.98 (PA9), U7.3 (IO2)
/PA10: PROGRAMMING_1.8, STM32H745ZIT6.99 (PA10), U7.1 (IO1)
/PA13: PROGRAMMING_1.3, STM32H745ZIT6.102 (PA13), U8.3 (IO2)
/PA14: PROGRAMMING_1.4, STM32H745ZIT6.107 (PA14), U8.1 (IO1)
/PB0: POT_DIGITAL_1.2, R21.1, STM32H745ZIT6.49 (PB0)
/PB1: POT_DIGITAL_1.3, R22.1, STM32H745ZIT6.50 (PB1)
/PB2: POT_DIGITAL_1.4, R23.1, STM32H745ZIT6.51 (PB2)
/PB3: PROGRAMMING_1.6, STM32H745ZIT6.130 (PB3), U7.4 (IO3)
/PB4: STM32H745ZIT6.131 (PB4)
/PB5: ELRS_2.6, STM32H745ZIT6.132 (PB5), U6.6 (IO4)
/PB6: STM32H745ZIT6.133 (PB6)
/PB7: STM32H745ZIT6.134 (PB7)
/PB8: ELRS_2.7, STM32H745ZIT6.136 (PB8), U6.4 (IO3)
/PB14: R49.2, R62.1, STM32H745ZIT6.74 (PB14), U3.6 (IO4)
/PB15: R48.2, R61.1, STM32H745ZIT6.75 (PB15), U3.4 (IO3)
/PC0: C32.2, R7.1, STM32H745ZIT6.28 (PC0)
/PC1: C33.2, R8.1, STM32H745ZIT6.29 (PC1)
/PC2: C34.2, R9.1, STM32H745ZIT6.30 (PC2_C)
/PC3: C35.2, R10.1, STM32H745ZIT6.31 (PC3_C)
/PC4: C36.2, R11.1, STM32H745ZIT6.47 (PC4)
/PC5: C37.2, R12.1, STM32H745ZIT6.48 (PC5)
/PC6: ENCODER_1.1, R27.1, STM32H745ZIT6.93 (PC6)
/PC7: ENCODER_1.2, R28.1, STM32H745ZIT6.94 (PC7)
/PC8: ENCODER_1.4, R29.1, STM32H745ZIT6.95 (PC8)
/PC9: ENCODER_1.5, R30.1, STM32H745ZIT6.96 (PC9)
/PC10: ENCODER_1.6, R31.1, STM32H745ZIT6.109 (PC10)
/PC11: ENCODER_1.7, R32.1, STM32H745ZIT6.110 (PC11)
/PC12: ENCODER_1.8, R33.1, STM32H745ZIT6.111 (PC12)
/PD0: R16.1, STM32H745ZIT6.112 (PD0), SWITCHES_1.2
/PD1: R17.1, STM32H745ZIT6.113 (PD1), SWITCHES_1.3
/PD2: R18.1, STM32H745ZIT6.114 (PD2), SWITCHES_1.4
/PD3: R19.1, STM32H745ZIT6.115 (PD3), SWITCHES_1.5
/PD4: R20.1, STM32H745ZIT6.116 (PD4), SWITCHES_1.6
/PD6: R50.2, STM32H745ZIT6.120 (PD6)
/PD7: R47.1, R60.2, STM32H745ZIT6.121 (PD7), U3.1 (IO1)
/PD8: ELRS_1.2, STM32H745ZIT6.76 (PD8), U5.3 (IO2)
/PD9: ELRS_1.4, STM32H745ZIT6.77 (PD9), U5.1 (IO1)
/PD10: ELRS_1.6, STM32H745ZIT6.78 (PD10), U5.6 (IO4)
/PD11: ELRS_1.7, STM32H745ZIT6.81 (PD11), U5.4 (IO3)
/PD12: ENCODER_2.1, R34.1, STM32H745ZIT6.82 (PD12)
/PD13: ENCODER_2.2, R35.1, STM32H745ZIT6.83 (PD13)
/PD14: ENCODER_2.4, R36.1, STM32H745ZIT6.84 (PD14)
/PD15: ENCODER_2.5, R37.1, STM32H745ZIT6.85 (PD15)
/PE2: SCREEN_1.4, STM32H745ZIT6.1 (PE2)
/PE3: SCREEN_1.7, STM32H745ZIT6.2 (PE3)
/PE4: SCREEN_1.6, STM32H745ZIT6.3 (PE4)
/PE5: SCREEN_1.5, STM32H745ZIT6.4 (PE5)
/PE6: SCREEN_1.3, STM32H745ZIT6.5 (PE6)
/PE7: ELRS_2.4, STM32H745ZIT6.57 (PE7), U6.3 (IO2)
/PE8: ELRS_2.2, STM32H745ZIT6.58 (PE8), U6.1 (IO1)
/PE9: SCREEN_1.8, STM32H745ZIT6.59 (PE9)
/PE10: BUTTONS_1.2, R13.1, STM32H745ZIT6.60 (PE10)
/PE11: BUTTONS_1.3, R14.1, STM32H745ZIT6.61 (PE11)
/PE12: BUTTONS_1.4, R15.1, STM32H745ZIT6.62 (PE12)
/PF11: POT_DIGITAL_1.5, R24.1, STM32H745ZIT6.52 (PF11)
/PF14: POT_DIGITAL_1.6, R25.1, STM32H745ZIT6.53 (PF14)
/PF15: POT_DIGITAL_1.7, R26.1, STM32H745ZIT6.54 (PF15)
/PG6: ENCODER_2.6, R38.1, STM32H745ZIT6.86 (PG6)
/PG7: ENCODER_2.7, R39.1, STM32H745ZIT6.87 (PG7)
/PG8: ENCODER_2.8, R40.1, STM32H745ZIT6.88 (PG8)
/PG11: R45.1, R58.2, STM32H745ZIT6.124 (PG11), U4.1 (IO1)
/PG12: R46.1, R59.2, STM32H745ZIT6.125 (PG12), U4.3 (IO2)
/PG13: R51.2, SD_CARD_1.10 (SW_DETECT), STM32H745ZIT6.126 (PG13), U4.6 (IO4)
/PH0: C23.2, STM32H745ZIT6.25 (PH0), XTAL1.1
/PH1: R56.2, STM32H745ZIT6.26 (PH1)
/RAW: POWER_1.3, R43.1
/SD_CLK: R50.1, SD_CARD_1.5 (CLK), U3.3 (IO2)
/USB_D_N: L2.2, STM32H745ZIT6.100 (PA11)
/USB_D_P: L2.3, STM32H745ZIT6.101 (PA12)
/USB_N: J1.A7 (D-), J1.B7 (D-), L2.1, U2.1 (IO1)
/USB_P: J1.A6 (D+), J1.B6 (D+), L2.4, U2.3 (IO2)
/VCAP: C22.1, C63.2, C64.1, L1.2, STM32H745ZIT6.17 (VFBSMPS), STM32H745ZIT6.68 (VCAP), STM32H745ZIT6.103 (VCAP), STM32H745ZIT6.140 (VCAP)
/VDDA: C45.2, C46.2, L3.1, R54.1, STM32H745ZIT6.36 (VDDA)
/VLXSMPS: C61.2, L1.1, STM32H745ZIT6.15 (VLXSMPS)
/VREF+: C19.1, C20.1, R54.2, STM32H745ZIT6.35 (VREF+)
GND: BUTTONS_1.1, C1.2, C2.2, C3.2, C4.1, C5.1, C6.1, C7.1, C8.1, C9.1, C10.1, C11.1, C12.1, C13.1, C14.1, C15.1, C16.1, C17.2, C18.2, C19.2, C20.2, C21.1, C22.2, C23.1, C24.2, C25.1, C26.1, C27.1, C28.1, C29.2, C30.2, C31.2, C32.1, C33.1, C34.1, C35.1, C36.1, C37.1, C38.2, C39.2, C40.2, C41.1, C42.1, C43.1, C44.1, C45.1, C46.1, C47.1, C48.1, C49.1, C50.2, C51.2, C52.1, C53.1, C54.1, C55.1, C56.1, C57.1, C58.1, C59.2, C60.2, C61.1, C62.1, C63.1, C64.2, ELRS_1.1, ELRS_1.3, ELRS_1.5, ELRS_1.8, ELRS_1.P1, ELRS_1.P2, ELRS_2.1, ELRS_2.3, ELRS_2.5, ELRS_2.8, ELRS_2.P1, ELRS_2.P2, ENCODER_1.3, ENCODER_2.3, J1.A1 (GND), J1.A12 (GND), J1.B1 (GND), J1.B12 (GND), JOYSTICK_1.1, JOYSTICK_1.3, JOYSTICK_1.5, JOYSTICK_2.1, JOYSTICK_2.3, JOYSTICK_2.5, LD1.2 (GND), LD2.2 (GND), LD3.2 (GND), LD4.2 (GND), POT_ANALOG_1.1, POT_DIGITAL_1.1, POWER_1.1, POWER_1.4, PROGRAMMING_1.2, R1.1, R41.2, R42.2, R44.2, R55.1, R57.2, SCREEN_1.1, SD_CARD_1.6 (VSS), SD_CARD_1.9 (SW_DETECT), STM32H745ZIT6.6 (VSS), STM32H745ZIT6.12 (VSS), STM32H745ZIT6.14 (VSSSMPS), STM32H745ZIT6.18 (VSS), STM32H745ZIT6.33 (VSS), STM32H745ZIT6.34 (VSSA), STM32H745ZIT6.41 (VSS), STM32H745ZIT6.55 (VSS), STM32H745ZIT6.69 (VSS), STM32H745ZIT6.80 (VSS), STM32H745ZIT6.89 (VSS), STM32H745ZIT6.104 (VSS), STM32H745ZIT6.118 (VSS), STM32H745ZIT6.128 (VSS), STM32H745ZIT6.141 (VSS), SWITCHES_1.1, TP2.1 (1_1), U2.2 (VN), U2.4 (IO3), U2.6 (IO4), U3.2 (VN), U4.2 (VN), U4.4 (IO3), U5.2 (VN), U6.2 (VN), U7.2 (VN), U8.2 (VN), U8.4 (IO3), U8.6 (IO4), XTAL1.2, XTAL1.4
unnamed: BUZZER_1.1, R52.2
unnamed: BUZZER_1.2, R53.2
unnamed: C24.1, R56.1, XTAL1.3
unnamed: J1.A5 (CC1), R42.1
unnamed: J1.B5 (CC2), R41.1
unnamed: C62.2, J1.S1 (SHIELD), R55.2
unnamed: JOYSTICK_1.2, R3.2
unnamed: JOYSTICK_1.4, R4.2
unnamed: JOYSTICK_2.2, R5.2
unnamed: JOYSTICK_2.4, R6.2
unnamed: POT_ANALOG_1.3, R7.2
unnamed: POT_ANALOG_1.4, R8.2
unnamed: POT_ANALOG_1.5, R9.2
unnamed: POT_ANALOG_1.6, R10.2
unnamed: POT_ANALOG_1.7, R11.2
unnamed: POT_ANALOG_1.8, R12.2
unnamed: R59.1, SD_CARD_1.2 (CD/DAT3)
unnamed: R60.1, SD_CARD_1.3 (CMD)
unnamed: R62.2, SD_CARD_1.7 (DAT0)
unnamed: R61.2, SD_CARD_1.8 (DAT1)
unnamed: R58.1, SD_CARD_1.1 (DAT2)
unnamed: R57.1, U1.1 (G)
VCC: C1.1, C17.1, C29.1, C40.1, LD1.1 (VIN), LD1.3 (EN), LD2.1 (VIN), LD2.3 (EN), LD3.1 (VIN), LD3.3 (EN), LD4.1 (VIN), LD4.3 (EN), U1.3 (D)

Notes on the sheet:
SWITCH_3
SW1
ENCB
POT3
POT1
SW5
RST
SWITCH_1
SWITCH_4
SW3
COMA
CLK
POT2
ENCA
POT7
BOOT
BTN2
SW4
POT4
BTN3
DIN
POT5
POT6
SWITCH_2
SW2
BTN1
SWITCH_5

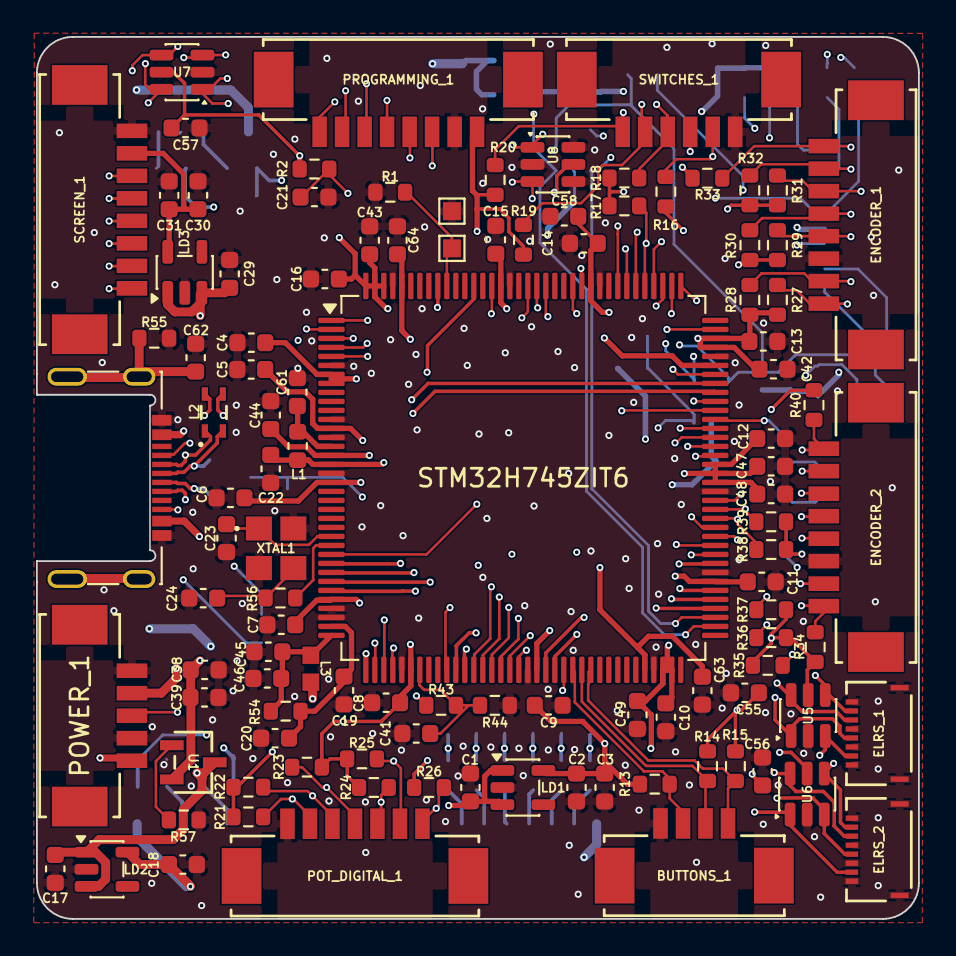
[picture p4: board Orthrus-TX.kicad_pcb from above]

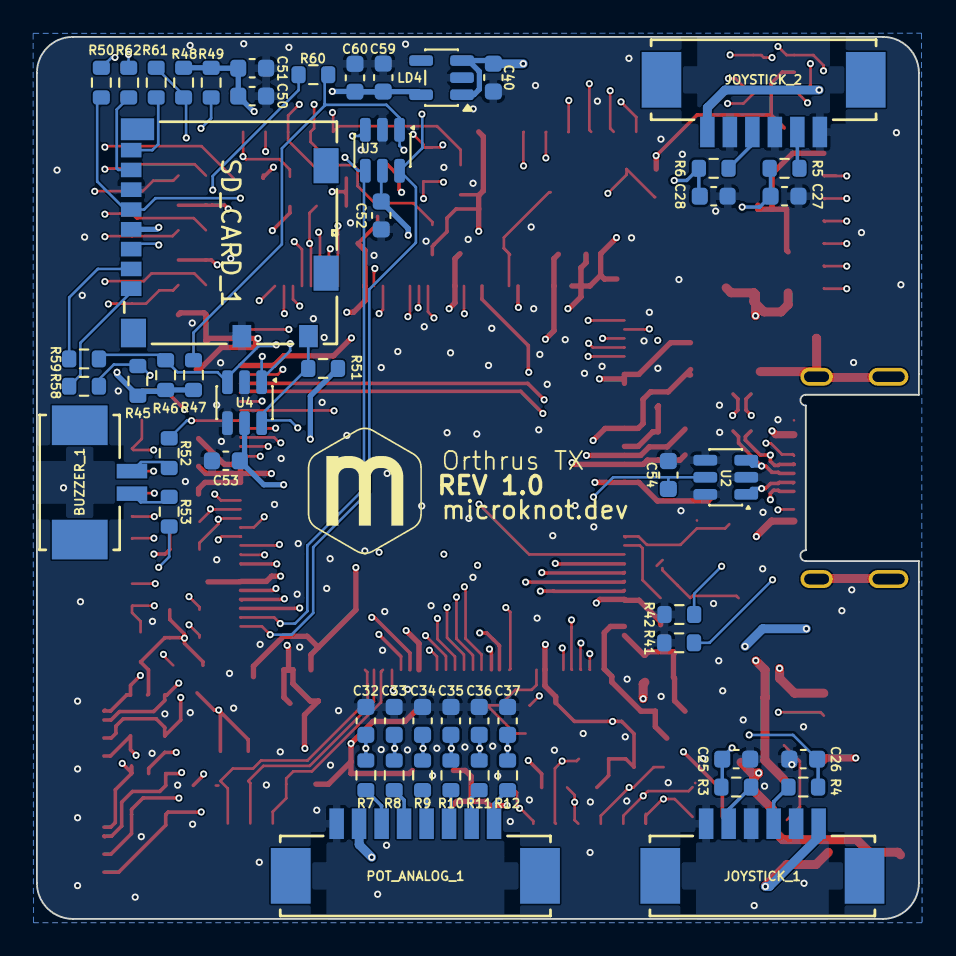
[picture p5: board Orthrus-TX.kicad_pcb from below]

Board: 8 copper layers, 49.0 x 49.0 mm, 162 parts (54 on the bottom side), 111 nets.

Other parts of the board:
Orthrus TX: REV 1.0; TX-Logo

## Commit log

2026-05-16 DRC update
    [Orthrus-TX.kicad_pcb]
2026-05-16 DRU updates
    [Orthrus-TX.kicad_pcb]
2026-05-16 pcb update
    [Orthrus-TX.kicad_pcb]
2026-05-16 extra GND vias
    [Orthrus-TX.kicad_pcb]
2026-05-16 adjust the USB traces
    [Orthrus-TX.kicad_pcb]
2026-05-16 small adjustment for the logo
    [Orthrus-TX.kicad_pcb]
2026-05-16 change signal order for joysticks
    [Orthrus-TX.kicad_pcb, Orthrus-TX.kicad_sch]
2026-05-17 add SRV05-4 for ELRS
    [Orthrus-TX.kicad_pcb, Orthrus-TX.kicad_sch]
2026-05-17 add SRV05-4 for programming/debugging
    [Orthrus-TX.kicad_pcb, Orthrus-TX.kicad_sch]
2026-05-21 Use Thermal Reliefs for L1 and L8
    [Orthrus-TX.kicad_pcb]
2026-05-21 extra LDO for the SDCard
    [Orthrus-TX.kicad_pcb, Orthrus-TX.kicad_sch]
2026-05-23 schematic/net update
2026-05-27 sd card routing update
    [Orthrus-TX.kicad_pcb, Orthrus-TX.kicad_sch]
2026-05-31 data update
    [Orthrus-TX.csv]
